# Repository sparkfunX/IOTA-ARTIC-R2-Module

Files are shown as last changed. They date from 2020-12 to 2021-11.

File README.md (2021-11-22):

# IOTA (Integrated Open-Source Transceiver for Argos)

SparkX IOTA (SPX-17984) (https://www.sparkfun.com/products/17984)

[*SparkX IOTA (SPX-17984)*](https://www.sparkfun.com/products/17984)

The [ARGOS ARTIC R2 satellite communication chipset](https://www.cls-telemetry.com/argos-solutions/argos-products/modems/artic-chipset/#1534863095666-398318f3-c367) in castellated module format.

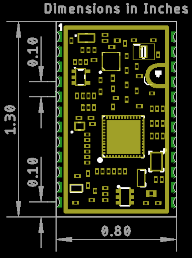
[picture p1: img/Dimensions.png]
Dimensions


The ARTIC-R2 is an integrated low power small size ARGOS 2/3/4 single chip radio. ARTIC-R2 implements a message based wireless interface. For satellite uplink communication, ARTIC-R2 will encode, modulate and transmit provided user messages. For downlink communication, ARTIC-R2 will lock to the downstream, demodulate and decode it and extract the satellite messages.

The ARTIC-R2 can transmit signals in frequency bands around 400MHz and receive signals in the bands around 466MHz, in accordance with the ARGOS satellite system specifications. The ARTIC-R2 is compliant to all ARGOS 3 and ARGOS 4 RX and TX standards. It contains a RF transceiver and frequency synthesizer and a digital baseband modem. The ARTIC-R2 contains an on-chip power amplifier delivering 1mW [0dBm] output power, that serves as an output for connecting an external high efficient PA. The (de)modulation algorithms run on an on-chip DSP. This software approach allows for retargeting the ARTIC for other applications. The DSP program can be retained on an external flash or the MCU.

- Serial interface (SPI) for communication with MCU
- Programmable DSP core on board to ensure flexibility
- RX frequency : 466MHz – TX frequency: 400MHz
- Fractional N frequency synthesis
- Supported TX standards:
  - BPSK: PTT-A2 (ARGOS 2), PTT-VLD (ARGOS 4)
  - QPSK: PTT-A3, PTT-ZE (ARGOS 3)
  - GMSK: PTT-HD (ARGOS 3), PTT-MD (ARGOS 4), PTT-HD (ARGOS 4)
- Supported RX standards:
  - BPSK: PMT-A3 (ARGOS 3)
  - DSSS OQPSK: PMT-A4 (ARGOS 4) not available
- Dedicated flash Interface to retain Firmware
- Support COSPAS-SARSAT standard
- Operates on external 26MHz reference clock
- Dual supply, 1.8V and 3.3V
- Integrated PA (0dBm) to combine with external PA

An RFPA0133 programmable gain power amplifier boosts the 0dBm (1mW) output from the ARTIC by up to 26dB, producing a maximum transmit power level of 400mW. The transmit power can be adjusted via the **G8** pad.

The ARGOS satellite system is **currently** restricted to specific programs and applications. Please check that your project meets these requirements before buying hardware. [CLS (France)](https://www.cls-telemetry.com/argos-solutions/) and the [Woods Hole Group (America)](https://www.clsamerica.com/science-with-argos) will be able to advise if your project meets the requirements.
- _**"To meet system use requirements, all programs using Argos have to be related in some way or other to environmental protection, awareness or study, or to protecting human life."**_

## Repository Contents

- [**/Documents**](./Hardware) - Datasheets, test certificates, etc.
- [**/Hardware**](./Hardware) - Eagle PCB, SCH and LBR design files
- [**LICENSE.md**](./LICENSE.md) - contains the licence information

## Documentation

- [**Arduino Library**](https://github.com/sparkfun/SparkFun_ARGOS_ARTIC_R2_Arduino_Library) - SparkFun ARGOS ARTIC R2 Arduino Library
- [**Hookup Guide**](https://learn.sparkfun.com/tutorials/iota-artic-r2-satellite-communication-module-hookup-guide) - a hookup guide for the SparkFun IOTA - Satellite Communication Module (ARTIC R2)

## Thanks

The ARTIC R2 circuit is a remix of the reference design kindly provided by the [Arribada Initiative](https://arribada.org/) and Icoteq Ltd.

## License Information

This product is _**open source**_! 

Please review the LICENSE.md file for license information. 

If you have any questions or concerns on licensing, please contact technical support on our [SparkFun forums](https://forum.sparkfun.com/viewforum.php?f=152).

Distributed as-is; no warranty is given.

- Your friends at SparkFun.

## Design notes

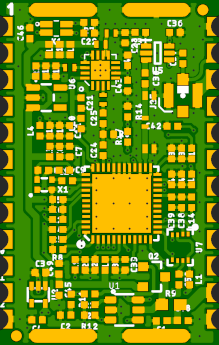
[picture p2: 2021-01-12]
img/Top.png

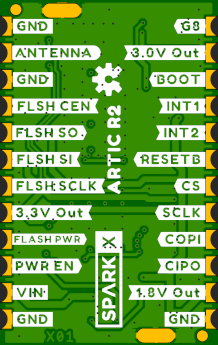
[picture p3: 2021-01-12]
img/Bottom.png

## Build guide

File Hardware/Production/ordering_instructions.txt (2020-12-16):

JLCPCB JLC7628 4-Layer 0.8mm Impedance Control
Castellated Holes
panel size, 148x148mm
PCB thickness, 0.8mm
number of layers, 4
soldermask color, Black
silkscreen color, White
oz copper, 1oz
finish, ENIG
stencils, top
pcs per panel, 20
min trace width, 0.2032mm / 0.0080in
min drill size, 0.2000mm / 0.0079in
filename to layer stackup 1/2/3/4: GTL, GL2, GL3, GBL

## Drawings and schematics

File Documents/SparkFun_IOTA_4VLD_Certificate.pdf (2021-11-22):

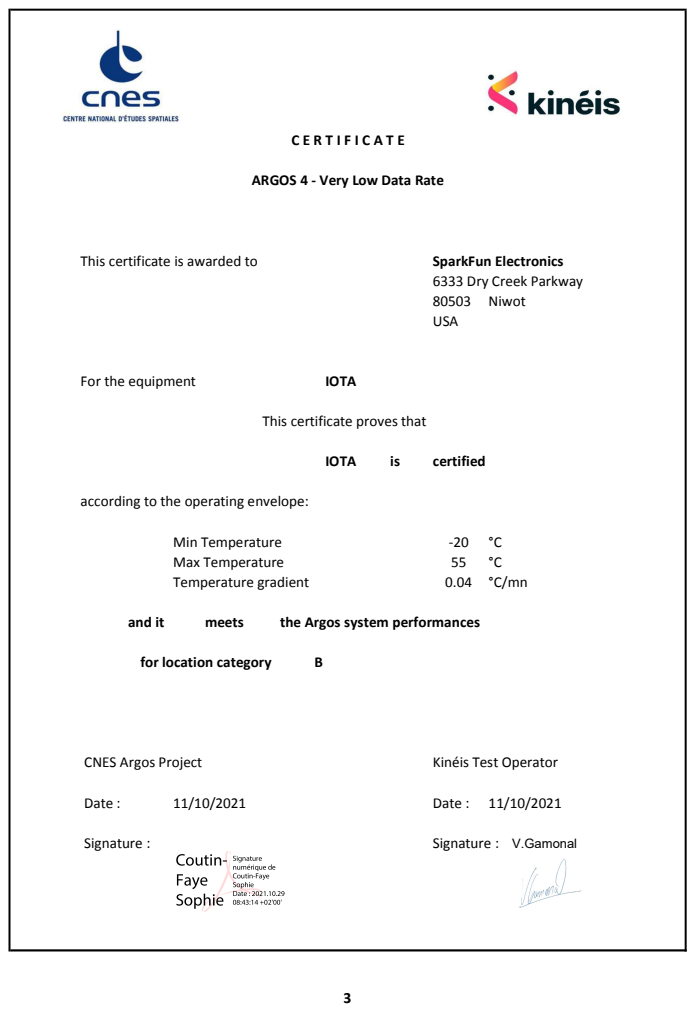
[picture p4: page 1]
This certificate is awarded to; SparkFun Electronics; For the equipment; IOTA; certified; Min Temperature; Max Temperature; Temperature gradient; and it; meets; the Argos system performances; for location category; CNES Argos Project; Kinéis Test Operator; Date :; Date : 11/10/2021; Signature :; V.Gamonal

ARGOS 4 - Very Low Data Rate

6333 Dry Creek Parkway
80503 Niwot
USA

This certificate proves that

according to the operating envelope:

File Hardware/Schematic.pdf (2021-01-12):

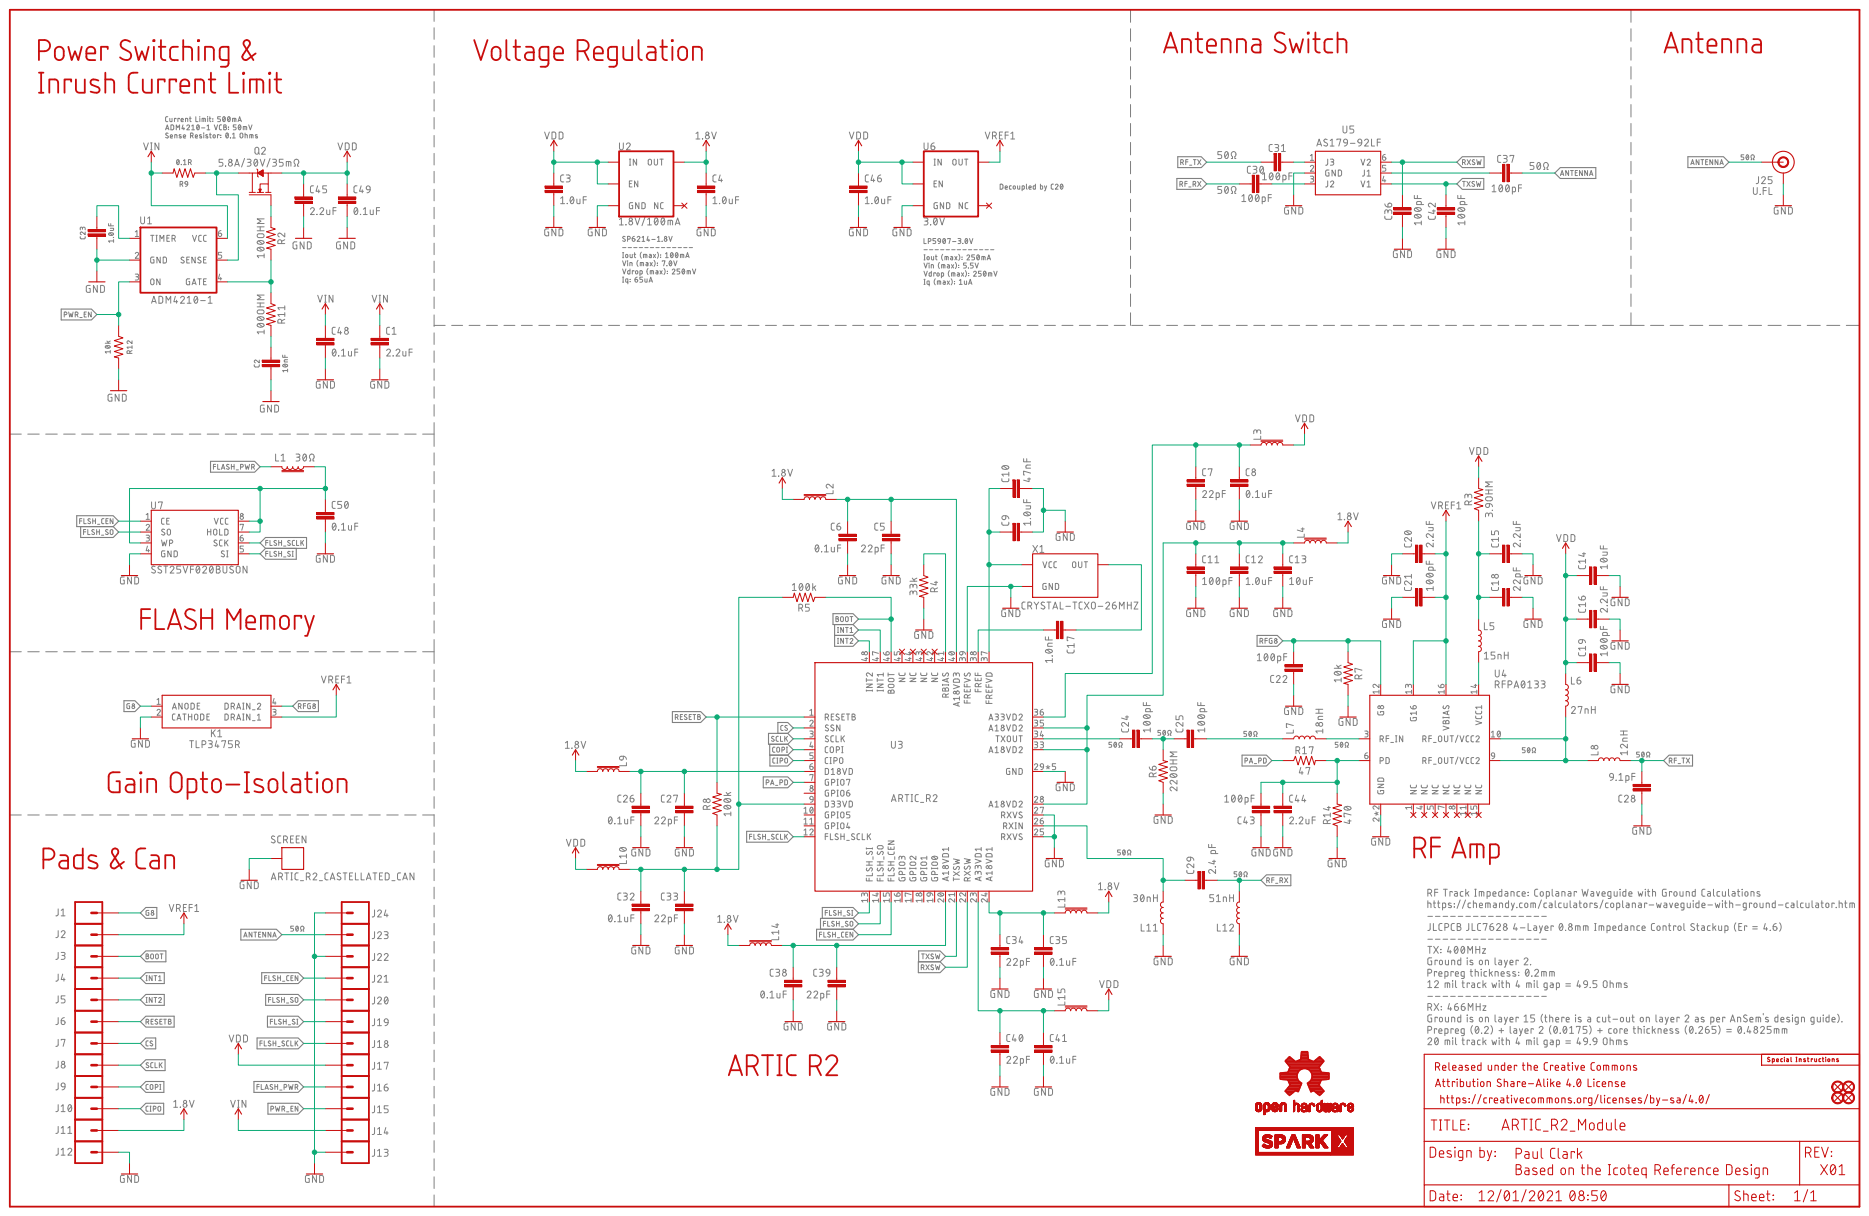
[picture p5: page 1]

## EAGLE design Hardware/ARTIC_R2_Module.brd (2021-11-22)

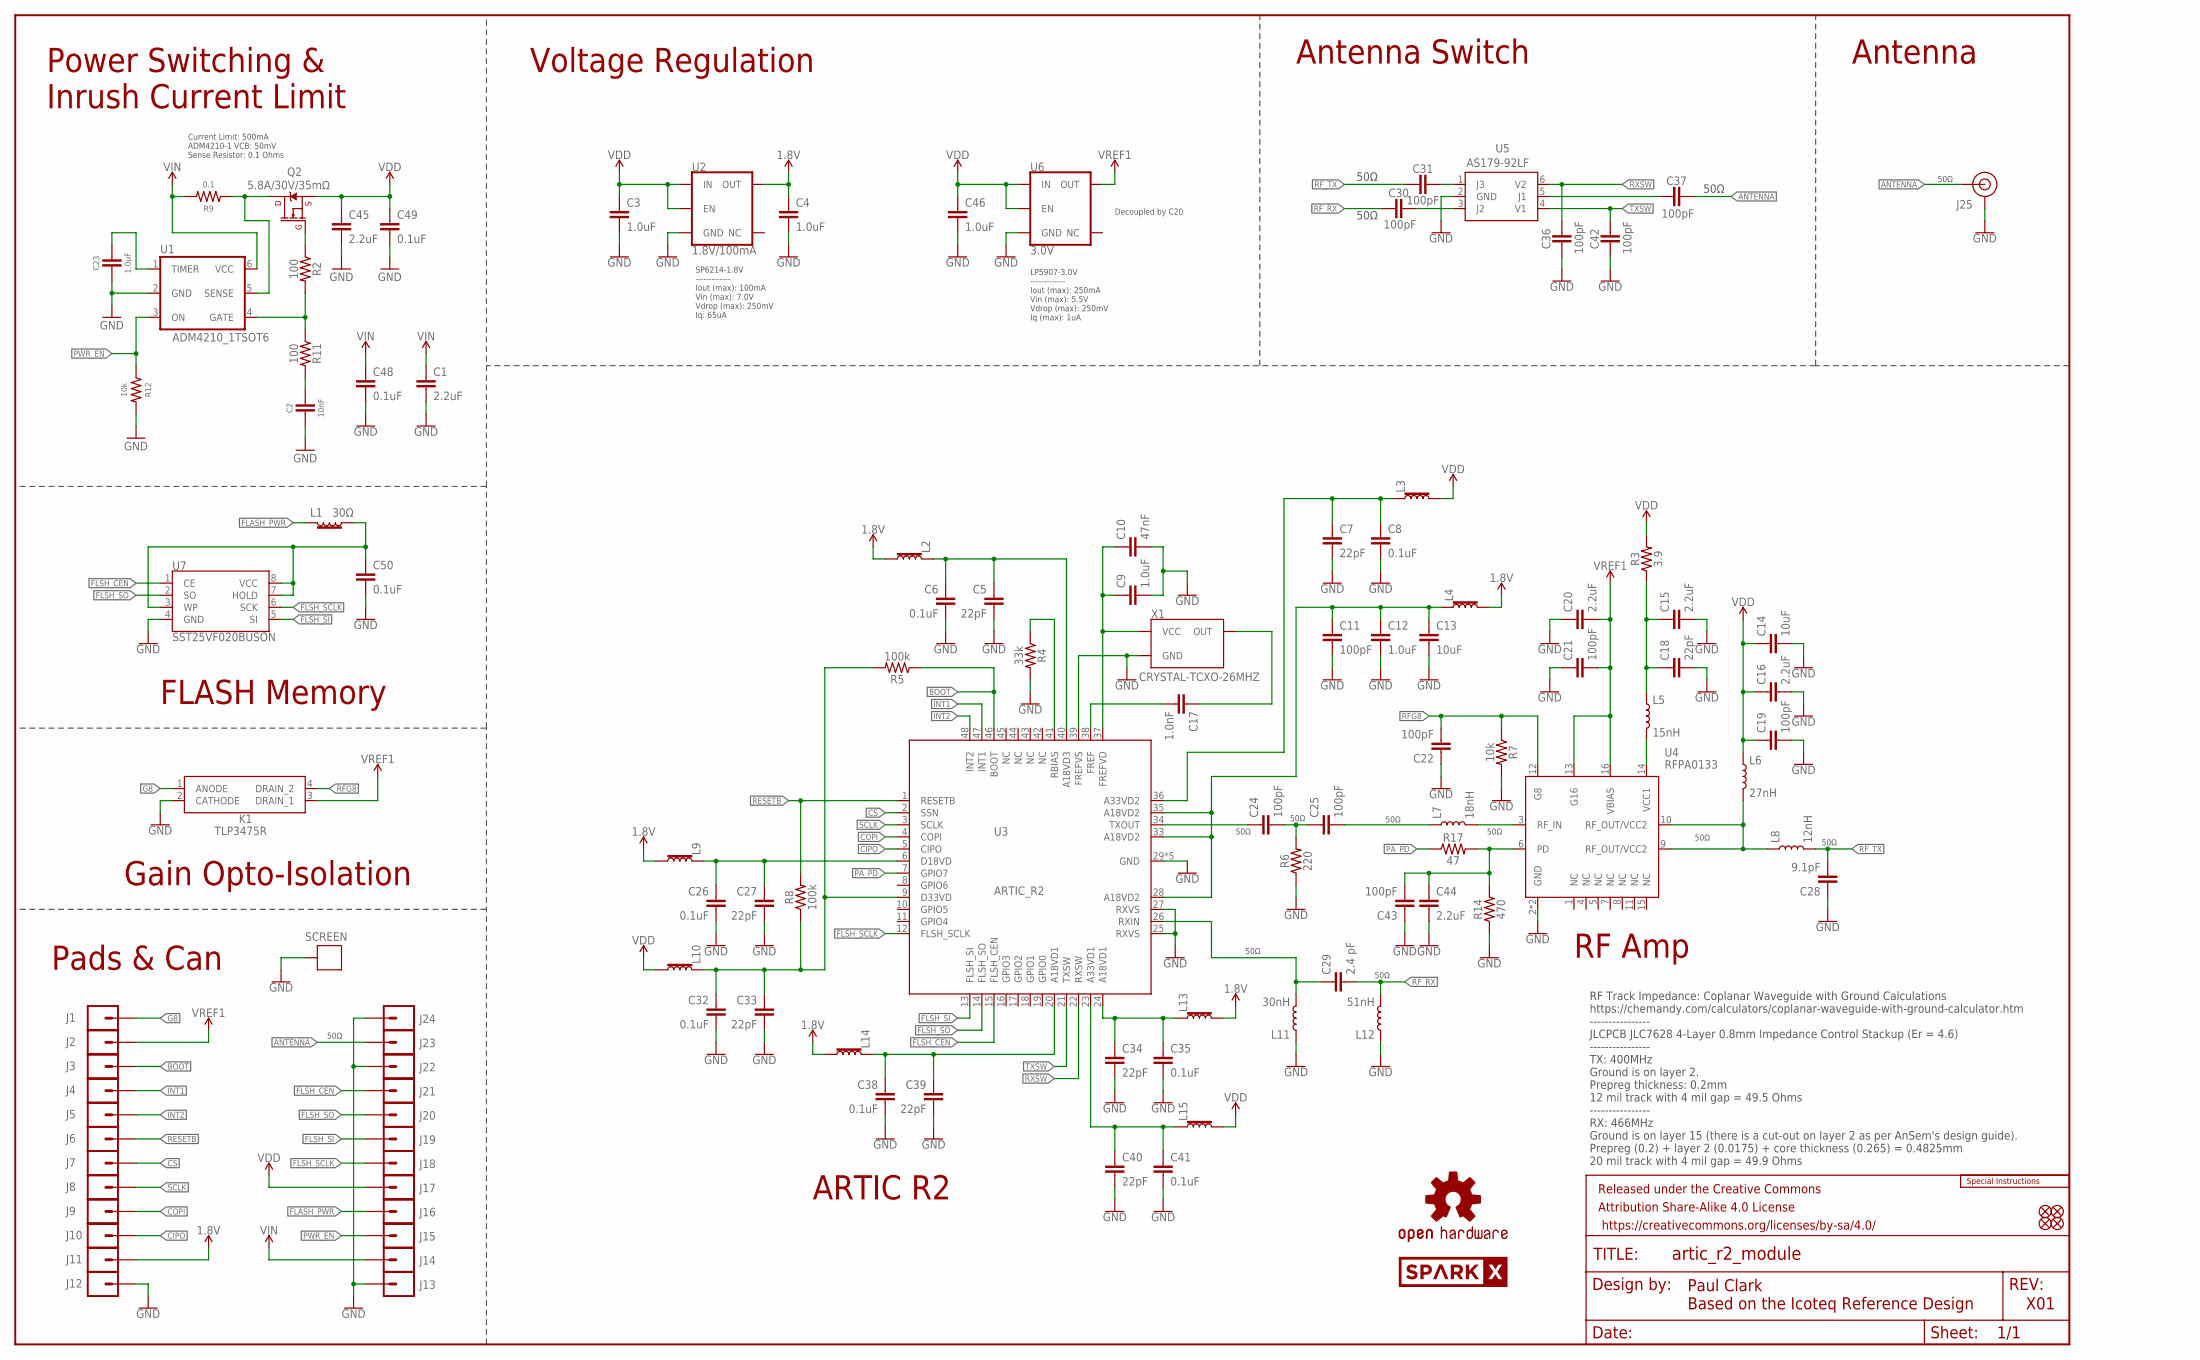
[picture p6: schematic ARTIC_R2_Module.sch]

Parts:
C1, C15, C16, C20, C44, C45: 2.2uF; 0402-TIGHT
C2: 10nF; 0402-TIGHT
C3, C4, C9, C12, C23, C46: 1.0uF; 0402-TIGHT
C5, C7, C18, C27, C33, C34, C39, C40: 22pF; 0402-TIGHT
C6, C8, C26, C32, C35, C38, C41, C48, C49, C50: 0.1uF; 0402-TIGHT
C10: 47nF; 0402-TIGHT
C11, C19, C21, C22, C24, C25, C30, C31, C36, C37, C42, C43: 100pF; 0402-TIGHT
C13, C14: 10uF; 0402-TIGHT
C17: 1.0nF; 0402-TIGHT
C28: 9.1pF; 0402-TIGHT
C29: 2.4 pF; 0402_MURATA
FD1, FD2, FD3, FD4: FIDUCIAL1X2; FIDUCIAL-1X2
FRAME1: FRAME-LEDGER; CREATIVE_COMMONS
J1, J2, J3, J4, J5, J6, J7, J8, J9, J10, J11, J12, J13, J14, J15, J16, J17, J18, J19, J20, J21, J22, J23, J24: CONN_01_CASTELLATED_4LAYERWITHOUT_VIA; CONN_01_CASTELLATED_4LAYER
J25: U.FL; U.FL_REDUCED_FOOTPRINT
K1: TLP3475R; TLP3475RTPF
L1, L2, L3, L4, L9, L10, L13, L14, L15: 30Ω; 0402-TIGHT
L5: 15nH; 0402_COILCRAFT
L6: 27nH; 0402_COILCRAFT
L7: 18nH; 0402_COILCRAFT
L8: 12nH; 0402_COILCRAFT
L11: 30nH; 0402_COILCRAFT
L12: 51nH; 0402_COILCRAFT
LOGO1: SPECIAL_INSTRUCTIONS-ORDERING; ORDERING_INSTRUCTIONS
LOGO3: OSHW-LOGOS; OSHW-LOGO-S
Q2: 5.8A/30V/35mΩ; SOT23-3
R2, R11: 100; 0402-TIGHT
R3: 3.9; 0402-TIGHT
R4: 33k; 0402-TIGHT
R5, R8: 100k; 0402-TIGHT
R6: 220; 0402-TIGHT
R7, R12: 10k; 0402-TIGHT
R9: 0.1; 0603
R14: 470; 0402-TIGHT
R17: 47; 0402-TIGHT
SCREEN: IOTA_SCREENING_CANSTRAIGHT_SLOTS; IOTA_CAN_STRAIGHT_SLOTS
SPARKX2: SPARKX-LOGO4; SPARKX-MEDIUM
U1: ADM4210_1TSOT6; TSOT6
U2: 1.8V/100mA; SC70
U3: ARTIC_R2; QFN-48
U4: RFPA0133; QFN50P300X300X86-17N
U5: AS179-92LF; SOT65P220X100-6N
U6: 3.0V; SOT23-5
U7: SST25VF020BUSON; USON_3X2MM
X1: CRYSTAL-TCXO-26MHZ; CRYSTAL-TCXO-SMD-1.65X1.25

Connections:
1.8V: C4.1, J11.1, L2.2, L4.2, L9.2, L13.2, L14.2, U2.5 (OUT)
ANTENNA: C37.1, J23.1, J25.FEED (SIGNAL)
BOOT: J3.1, R5.1, U3.46 (BOOT)
CIPO: J10.1, U3.5 (CIPO)
COPI: J9.1, U3.4 (COPI)
CS: J7.1, U3.2 (SSN)
FLASH_PWR: J16.1, L1.2
FLASH_VCC: C50.1, L1.1, U7.3 (WP), U7.7 (HOLD), U7.8 (VCC)
FLSH_CEN: J21.1, U3.15 (FLSH_CEN), U7.1 (CE)
FLSH_SCLK: J18.1, U3.12 (FLSH_SCLK), U7.6 (SCK)
FLSH_SI: J19.1, U3.13 (FLSH_SI), U7.5 (SI)
FLSH_SO: J20.1, U3.14 (FLSH_SO), U7.2 (SO)
G8: J1.1, K1.1 (ANODE)
GND: C1.2, C2.2, C3.2, C4.2, C5.2, C6.2, C7.2, C8.2, C9.2, C10.2, C11.2, C12.2, C13.2, C14.2, C15.2, C16.2, C18.2, C19.2, C20.1, C21.1, C22.1, C23.2, C26.2, C27.2, C28.1, C32.2, C33.2, C34.2, C35.2, C36.2, C38.2, C39.2, C40.2, C41.2, C42.2, C43.1, C44.2, C45.2, C46.2, C48.2, C49.2, C50.2, J12.1, J13.1, J22.1, J24.1, J25.1 (GND), J25.2 (GND), K1.2 (CATHODE), L11.P$1 (1), L12.P$1 (1), R4.2, R6.1, R7.2, R12.2, R14.1, SCREEN.1-1, SCREEN.1-16, SCREEN.2, SCREEN.3-1, SCREEN.3-16, SCREEN.4, U1.2 (GND), U2.2 (GND), U3.25 (RXVS), U3.27 (RXVS), U3.29 (GND), U3.30 (GND), U3.31 (GND), U3.32 (GND), U3.39 (FREFVS), U3.GND, U4.2 (GND), U4.EDAP (GND), U5.2 (GND), U6.2 (GND), U7.4 (GND), X1.1 (GND), X1.2 (GND)
INT1: J4.1, U3.47 (INT1)
INT2: J5.1, U3.48 (INT2)
unnamed: Q2.3 (D), R9.1, U1.5 (SENSE)
unnamed: Q2.1 (G), R2.1
unnamed: R2.2, R11.1, U1.4 (GATE)
unnamed: C34.1, C35.1, L13.1, U3.24 (A18VD1)
unnamed: C40.1, C41.1, L15.1, U3.23 (A33VD1)
unnamed: C2.1, R11.2
unnamed: C23.1, U1.1 (TIMER)
unnamed: C26.1, C27.1, L9.1, U3.6 (D18VD)
unnamed: C32.1, C33.1, L10.1, R5.2, R8.1, U3.9 (D33VD)
unnamed: C11.1, C12.1, C13.1, L4.1, U3.28 (A18VD2), U3.33 (A18VD2), U3.35 (A18VD2)
unnamed: C7.1, C8.1, L3.1, U3.36 (A33VD2)
unnamed: R4.1, U3.41 (RBIAS)
unnamed: C5.1, C6.1, L2.1, U3.40 (A18VD3)
unnamed: C9.1, C10.1, U3.37 (FREFVD), X1.4 (VCC)
unnamed: C17.1, X1.3 (OUT)
unnamed: C17.2, U3.38 (FREF)
unnamed: C24.1, U3.34 (TXOUT)
unnamed: C24.2, C25.1, R6.2
unnamed: L5.P$2 (2), U4.14 (VCC1)
unnamed: C15.1, C18.1, L5.P$1 (1), R3.1
unnamed: C29.P$1 (1), L11.P$2 (2), U3.26 (RXIN)
unnamed: C25.2, L7.P$1 (1)
unnamed: L7.P$2 (2), U4.3 (RF_IN)
unnamed: L6.P$2 (2), L8.P$1 (1), U4.9 (RF_OUT/VCC2), U4.10 (RF_OUT/VCC2)
unnamed: C31.1, U5.1 (J3)
unnamed: C30.1, U5.3 (J2)
unnamed: C37.2, U5.5 (J1)
unnamed: C38.1, C39.1, L14.1, U3.20 (A18VD1)
PA_PD: R17.1, U3.7 (GPIO7)
PD: C43.2, C44.1, R14.2, R17.2, U4.6 (PD)
PWR_EN: J15.1, R12.1, U1.3 (ON)
RESETB: J6.1, R8.2, U3.1 (RESETB)
RFG8: C22.2, K1.4 (DRAIN_2), R7.1, U4.12 (G8)
RF_RX: C29.P$2 (2), C30.2, L12.P$2 (2)
RF_TX: C28.2, C31.2, L8.P$2 (2)
RXSW: C36.1, U3.22 (RXSW), U5.6 (V2)
SCLK: J8.1, U3.3 (SCLK)
TXSW: C42.1, U3.21 (TXSW), U5.4 (V1)
VDD: C3.1, C14.1, C16.1, C19.1, C45.1, C46.1, C49.1, J17.1, L3.2, L6.P$1 (1), L10.2, L15.2, Q2.2 (S), R3.2, U2.1 (IN), U2.3 (EN), U6.1 (IN), U6.3 (EN)
VIN: C1.1, C48.1, J14.1, R9.2, U1.6 (VCC)
VREF1: C20.2, C21.2, J2.1, K1.3 (DRAIN_1), U4.13 (G16), U4.16 (VBIAS), U6.5 (OUT)

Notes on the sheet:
Paul Clark Based on the Icoteq Reference Design
X01
SP6214-1.8V ------------- Iout (max): 100mA Vin (max): 7.0V Vdrop (max): 250mV Iq: 65uA
Voltage Regulation
Antenna Switch
Antenna
ARTIC R2
RF Amp
Pads & Can
50Ω
RF Track Impedance: Coplanar Waveguide with Ground Calculations https://chemandy.com/calculators/coplanar-waveguide-with-ground-calculator.htm ---------------- JLCPCB JLC7628 4-Layer 0.8mm Impedance Control Stackup (Er = 4.6) ---------------- TX: 400MHz Ground is on layer 2. Prepreg thickness: 0.2m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
Gain Opto-Isolation
LP5907-3.0V ------------- Iout (max): 250mA Vin (max): 5.5V Vdrop (max): 250mV Iq (max): 1uA
Decoupled by C20
Power Switching & Inrush Current Limit
Current Limit: 500mA ADM4210-1 VCB: 50mV Sense Resistor: 0.1 Ohms
FLASH Memory

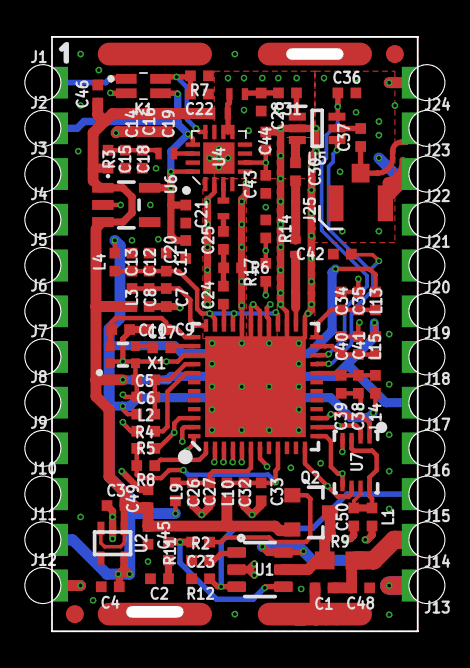
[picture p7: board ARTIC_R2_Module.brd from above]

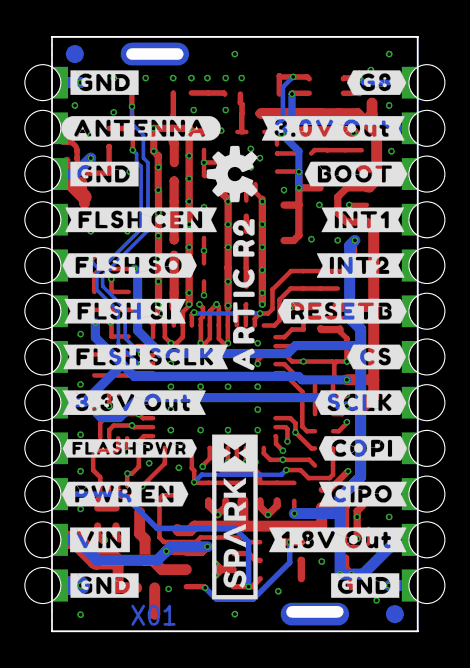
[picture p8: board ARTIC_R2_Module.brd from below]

Board: 4 copper layers, 20.3 x 33.0 mm, 146 parts (29 on the bottom side), 57 nets.

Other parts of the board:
U$1, U$3, U$4, U$5: #GND#0
U$2: 10
U$6: #PWR_EN#0
U$7: #VIN#0
U$8: #FLASH_PWR#0
U$9: #FLSH_SCLK#0
U$10: #FLSH_SI#0
U$11: #FLSH_SO#0
U$12: #FLSH_CEN#0
U$13: #3#3V_OUT#0
U$14: #ANTENNA#0
U$15: #G8#0
U$16: #3#0V_OUT#0
U$17: #BOOT#0
U$18: #INT1#0
U$19: #INT2#0
U$20: #RESETB#0
U$21: #CS#0
U$22: #SCLK#0
U$23: #COPI#0
U$24: #CIPO#0
U$25: #1#8V_OUT#0
U$26: ARTIC_R20

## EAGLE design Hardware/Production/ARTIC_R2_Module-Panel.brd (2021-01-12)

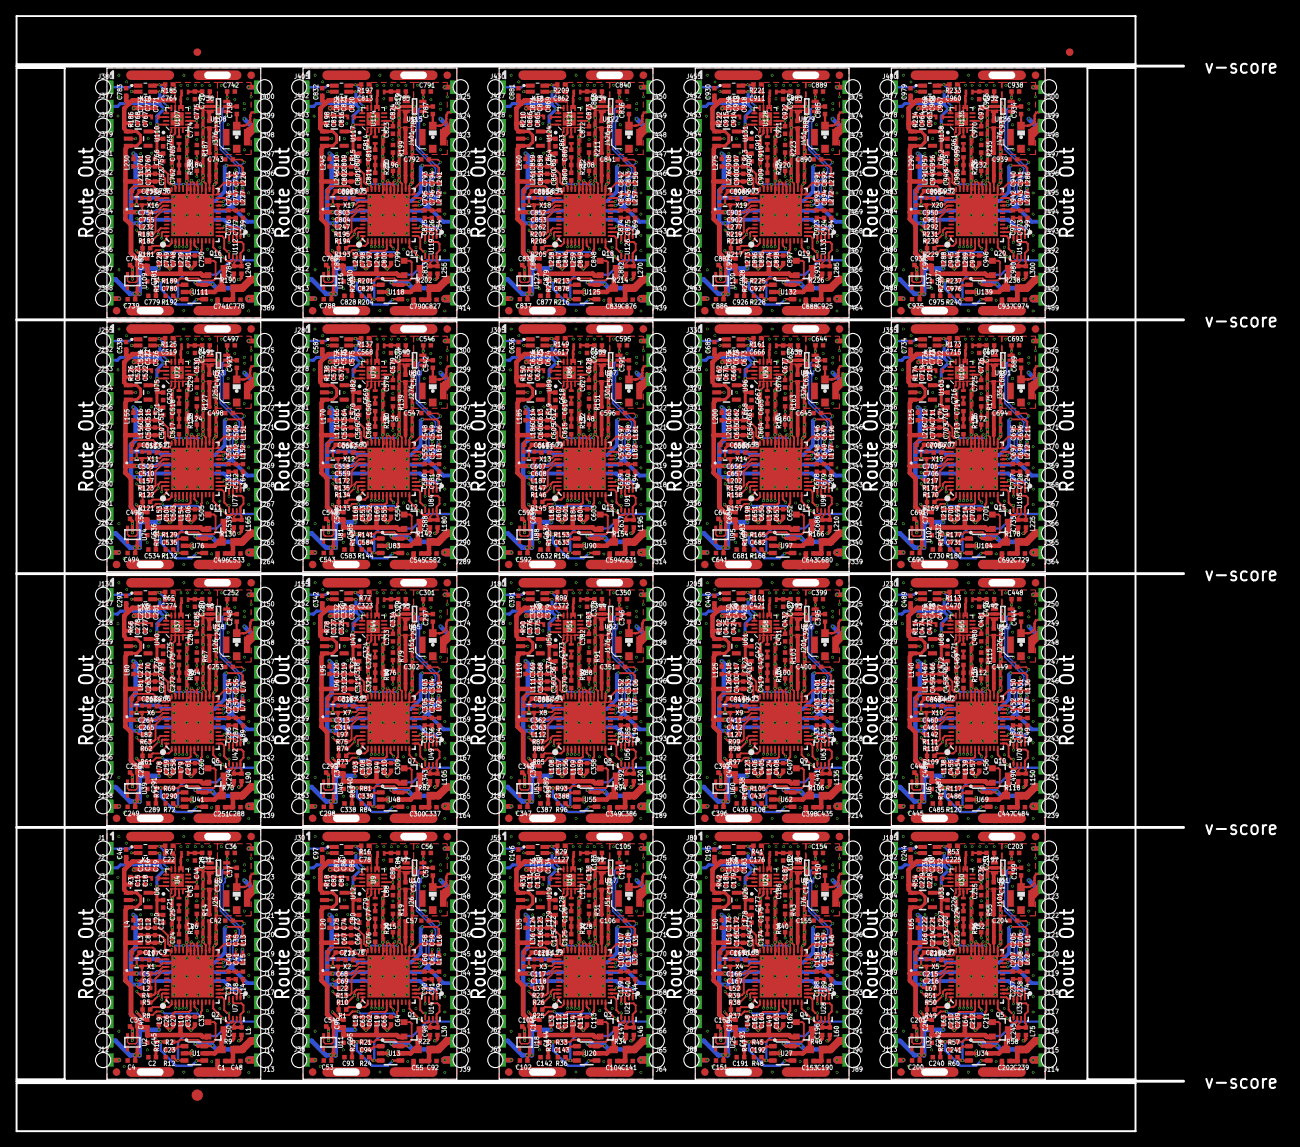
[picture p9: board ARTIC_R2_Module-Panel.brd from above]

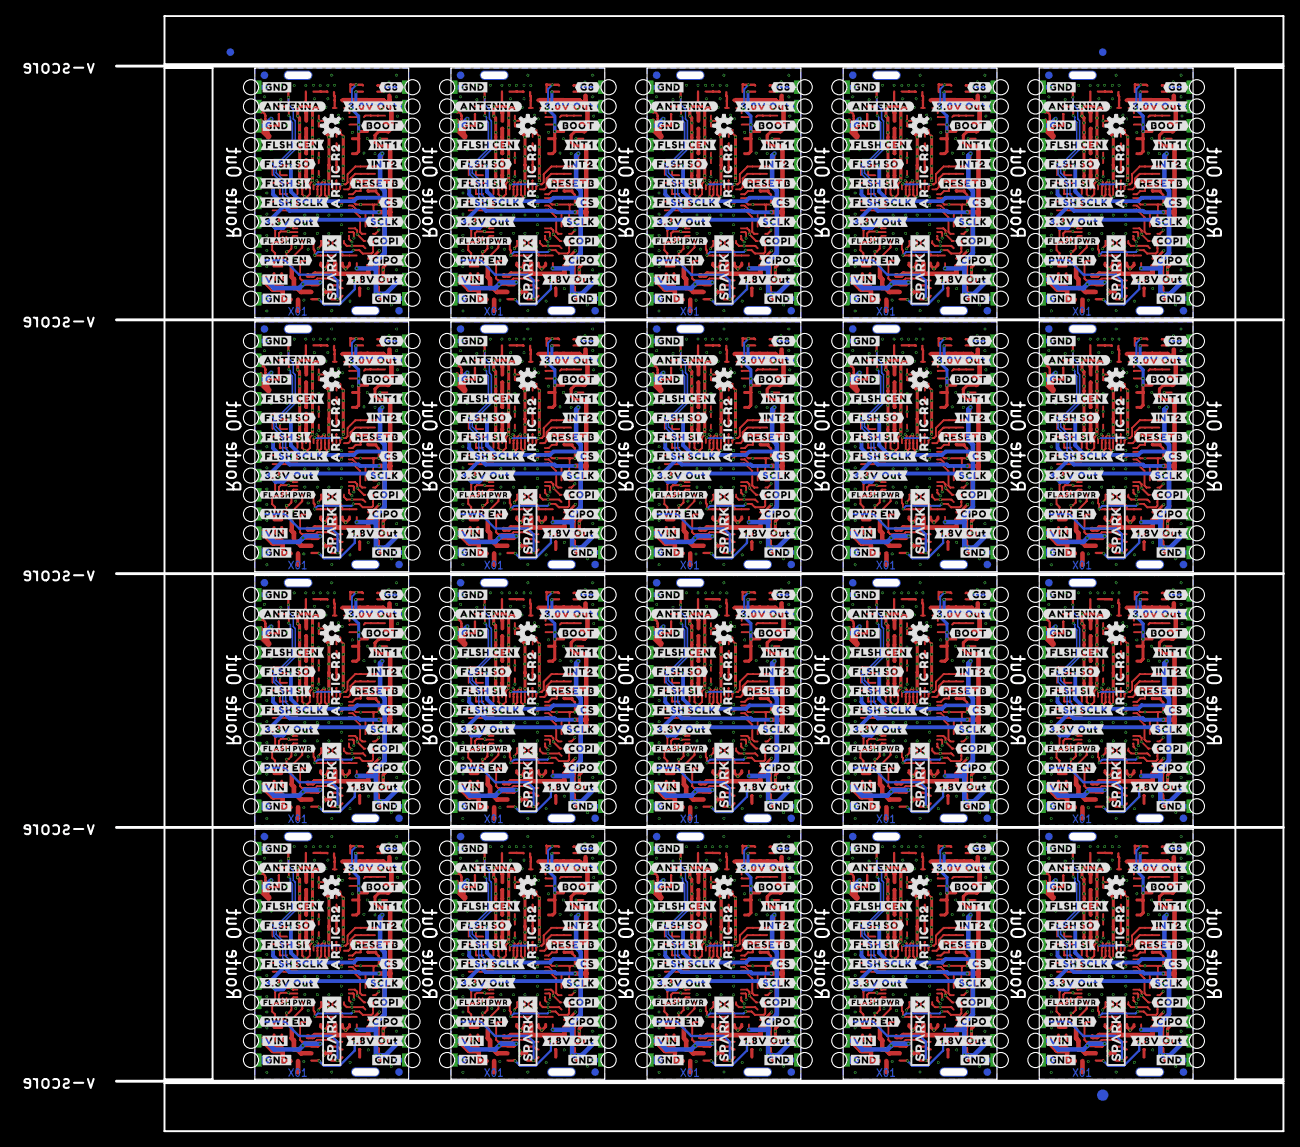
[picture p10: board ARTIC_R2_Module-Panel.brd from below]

Board: 4 copper layers, 154.2 x 147.3 mm, 2886 parts (583 on the bottom side), 1140 nets.

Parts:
C1, C15, C16, C20, C44, C45, C55, C80, C82, C86, C89, C95, C104, C129, C131, C135, C138, C144, C153, C178, C180, C184, C187, C193, C202, C227, C229, C233, C236, C242, C251, C276, C278, C282, C285, C291, C300, C325, C327, C331, C334, C340, C349, C374, C376, C380, C383, C389, C398, C423, C425, C429, C432, C438, C447, C472, C474, C478, C481, C487, C496, C521, C523, C527, C530, C536, C545, C570, C572, C576, C579, C585, C594, C619, C621, C625, C628, C634, C643, C668, C670, C674, C677, C683, C692, C717, C719, C723, C726, C732, C741, C766, C768, C772, C775, C781, C790, C815, C817, C821, C824, C830, C839, C864, C866, C870, C873, C879, C888, C913, C915, C919, C922, C928, C937, C962, C964, C968, C971, C977: 2.2uF; 0402-TIGHT
C2, C93, C142, C191, C240, C289, C338, C387, C436, C485, C534, C583, C632, C681, C730, C779, C828, C877, C926, C975: 10nF; 0402-TIGHT
C3, C4, C9, C12, C23, C46, C53, C54, C70, C74, C94, C97, C102, C103, C119, C123, C143, C146, C151, C152, C168, C172, C192, C195, C200, C201, C217, C221, C241, C244, C249, C250, C266, C270, C290, C293, C298, C299, C315, C319, C339, C342, C347, C348, C364, C368, C388, C391, C396, C397, C413, C417, C437, C440, C445, C446, C462, C466, C486, C489, C494, C495, C511, C515, C535, C538, C543, C544, C560, C564, C584, C587, C592, C593, C609, C613, C633, C636, C641, C642, C658, C662, C682, C685, C690, C691, C707, C711, C731, C734, C739, C740, C756, C760, C780, C783, C788, C789, C805, C809, C829, C832, C837, C838, C854, C858, C878, C881, C886, C887, C903, C907, C927, C930, C935, C936, C952, C956, C976, C979: 1.0uF; 0402-TIGHT
C5, C7, C18, C27, C33, C34, C39, C40, C58, C60, C62, C64, C66, C68, C81, C90, C107, C109, C111, C113, C115, C117, C130, C139, C156, C158, C160, C162, C164, C166, C179, C188, C205, C207, C209, C211, C213, C215, C228, C237, C254, C256, C258, C260, C262, C264, C277, C286, C303, C305, C307, C309, C311, C313, C326, C335, C352, C354, C356, C358, C360, C362, C375, C384, C401, C403, C405, C407, C409, C411, C424, C433, C450, C452, C454, C456, C458, C460, C473, C482, C499, C501, C503, C505, C507, C509, C522, C531, C548, C550, C552, C554, C556, C558, C571, C580, C597, C599, C601, C603, C605, C607, C620, C629, C646, C648, C650, C652, C654, C656, C669, C678, C695, C697, C699, C701, C703, C705, C718, C727, C744, C746, C748, C750, C752, C754, C767, C776, C793, C795, C797, C799, C801, C803, C816, C825, C842, C844, C846, C848, C850, C852, C865, C874, C891, C893, C895, C897, C899, C901, C914, C923, C940, C942, C944, C946, C948, C950, C963, C972: 22pF; 0402-TIGHT
C6, C8, C26, C32, C35, C38, C41, C48, C49, C50, C59, C61, C63, C65, C67, C69, C91, C92, C96, C98, C108, C110, C112, C114, C116, C118, C140, C141, C145, C147, C157, C159, C161, C163, C165, C167, C189, C190, C194, C196, C206, C208, C210, C212, C214, C216, C238, C239, C243, C245, C255, C257, C259, C261, C263, C265, C287, C288, C292, C294, C304, C306, C308, C310, C312, C314, C336, C337, C341, C343, C353, C355, C357, C359, C361, C363, C385, C386, C390, C392, C402, C404, C406, C408, C410, C412, C434, C435, C439, C441, C451, C453, C455, C457, C459, C461, C483, C484, C488, C490, C500, C502, C504, C506, C508, C510, C532, C533, C537, C539, C549, C551, C553, C555, C557, C559, C581, C582, C586, C588, C598, C600, C602, C604, C606, C608, C630, C631, C635, C637, C647, C649, C651, C653, C655, C657, C679, C680, C684, C686, C696, C698, C700, C702, C704, C706, C728, C729, C733, C735, C745, C747, C749, C751, C753, C755, C777, C778, C782, C784, C794, C796, C798, C800, C802, C804, C826, C827, C831, C833, C843, C845, C847, C849, C851, C853, C875, C876, C880, C882, C892, C894, C896, C898, C900, C902, C924, C925, C929, C931, C941, C943, C945, C947, C949, C951, C973, C974, C978, C980: 0.1uF; 0402-TIGHT
C10, C71, C120, C169, C218, C267, C316, C365, C414, C463, C512, C561, C610, C659, C708, C757, C806, C855, C904, C953: 47nF; 0402-TIGHT
C11, C19, C21, C22, C24, C25, C30, C31, C36, C37, C42, C43, C47, C51, C52, C56, C57, C73, C76, C77, C78, C79, C85, C88, C99, C100, C101, C105, C106, C122, C125, C126, C127, C128, C134, C137, C148, C149, C150, C154, C155, C171, C174, C175, C176, C177, C183, C186, C197, C198, C199, C203, C204, C220, C223, C224, C225, C226, C232, C235, C246, C247, C248, C252, C253, C269, C272, C273, C274, C275, C281, C284, C295, C296, C297, C301, C302, C318, C321, C322, C323, C324, C330, C333, C344, C345, C346, C350, C351, C367, C370, C371, C372, C373, C379, C382, C393, C394, C395, C399, C400, C416, C419, C420, C421, C422, C428, C431, C442, C443, C444, C448, C449, C465, C468, C469, C470, C471, C477, C480, C491, C492, C493, C497, C498, C514, C517, C518, C519, C520, C526, C529, C540, C541, C542, C546, C547, C563, C566, C567, C568, C569, C575, C578, C589, C590, C591, C595, C596, C612, C615, C616, C617, C618, C624, C627, C638, C639, C640, C644, C645, C661, C664, C665, C666, C667, C673, C676, C687, C688, C689, C693, C694, C710, C713, C714, C715, C716, C722, C725, C736, C737, C738, C742, C743, C759, C762, C763, C764, C765, C771, C774, C785, C786, C787, C791, C792, C808, C811, C812, C813, C814, C820, C823, C834, C835, C836, C840, C841, C857, C860, C861, C862, C863, C869, C872, C883, C884, C885, C889, C890, C906, C909, C910, C911, C912, C918, C921, C932, C933, C934, C938, C939, C955, C958, C959, C960, C961, C967, C970: 100pF; 0402-TIGHT
C13, C14, C75, C87, C124, C136, C173, C185, C222, C234, C271, C283, C320, C332, C369, C381, C418, C430, C467, C479, C516, C528, C565, C577, C614, C626, C663, C675, C712, C724, C761, C773, C810, C822, C859, C871, C908, C920, C957, C969: 10uF; 0402-TIGHT
C17, C72, C121, C170, C219, C268, C317, C366, C415, C464, C513, C562, C611, C660, C709, C758, C807, C856, C905, C954: 1.0nF; 0402-TIGHT
C28, C84, C133, C182, C231, C280, C329, C378, C427, C476, C525, C574, C623, C672, C721, C770, C819, C868, C917, C966: 9.1pF; 0402-TIGHT
C29, C83, C132, C181, C230, C279, C328, C377, C426, C475, C524, C573, C622, C671, C720, C769, C818, C867, C916, C965: 2.4 pF; 0402_MURATA
E$1, E$2, E$3, E$4: FIDUCIAL-1X2
E$5, E$6: FIDUCIAL-1.5X3
FD1, FD2, FD3, FD4, FD5, FD6, FD7, FD8, FD9, FD10, FD11, FD12, FD13, FD14, FD15, FD16, FD17, FD18, FD19, FD20, FD21, FD22, FD23, FD24, FD25, FD26, FD27, FD28, FD29, FD30, FD31, FD32, FD33, FD34, FD35, FD36, FD37, FD38, FD39, FD40, FD41, FD42, FD43, FD44, FD45, FD46, FD47, FD48, FD49, FD50, FD51, FD52, FD53, FD54, FD55, FD56, FD57, FD58, FD59, FD60, FD61, FD62, FD63, FD64, FD65, FD66, FD67, FD68, FD69, FD70, FD71, FD72, FD73, FD74, FD75, FD76, FD77, FD78, FD79, FD80: FIDUCIAL1X2; FIDUCIAL-1X2
J1, J2, J3, J4, J5, J6, J7, J8, J9, J10, J11, J12, J13, J14, J15, J16, J17, J18, J19, J20, J21, J22, J23, J24, J27, J28, J29, J30, J31, J32, J33, J34, J35, J36, J37, J38, J39, J40, J41, J42, J43, J44, J45, J46, J47, J48, J49, J50, J52, J53, J54, J55, J56, J57, J58, J59, J60, J61, J62, J63, J64, J65, J66, J67, J68, J69, J70, J71, J72, J73, J74, J75, J77, J78, J79, J80, J81, J82, J83, J84, J85, J86, J87, J88, J89, J90, J91, J92, J93, J94, J95, J96, J97, J98, J99, J100, J102, J103, J104, J105, J106, J107, J108, J109, J110, J111, J112, J113, J114, J115, J116, J117, J118, J119, J120, J121, J122, J123, J124, J125, J127, J128, J129, J130, J131, J132, J133, J134, J135, J136, J137, J138, J139, J140, J141, J142, J143, J144, J145, J146, J147, J148, J149, J150, J152, J153, J154, J155, J156, J157, J158, J159, J160, J161, J162, J163, J164, J165, J166, J167, J168, J169, J170, J171, J172, J173, J174, J175, J177, J178, J179, J180, J181, J182, J183, J184, J185, J186, J187, J188, J189, J190, J191, J192, J193, J194, J195, J196, J197, J198, J199, J200, J202, J203, J204, J205, J206, J207, J208, J209, J210, J211, J212, J213, J214, J215, J216, J217, J218, J219, J220, J221, J222, J223, J224, J225, J227, J228, J229, J230, J231, J232, J233, J234, J235, J236, J237, J238, J239, J240, J241, J242, J243, J244, J245, J246, J247, J248, J249, J250, J252, J253, J254, J255, J256, J257, J258, J259, J260, J261, J262, J263, J264, J265, J266, J267, J268, J269, J270, J271, J272, J273, J274, J275, J277, J278, J279, J280, J281, J282, J283, J284, J285, J286, J287, J288, J289, J290, J291, J292, J293, J294, J295, J296, J297, J298, J299, J300, J302, J303, J304, J305, J306, J307, J308, J309, J310, J311, J312, J313, J314, J315, J316, J317, J318, J319, J320, J321, J322, J323, J324, J325, J327, J328, J329, J330, J331, J332, J333, J334, J335, J336, J337, J338, J339, J340, J341, J342, J343, J344, J345, J346, J347, J348, J349, J350, J352, J353, J354, J355, J356, J357, J358, J359, J360, J361, J362, J363, J364, J365, J366, J367, J368, J369, J370, J371, J372, J373, J374, J375, J377, J378, J379, J380, J381, J382, J383, J384, J385, J386, J387, J388, J389, J390, J391, J392, J393, J394, J395, J396, J397, J398, J399, J400, J402, J403, J404, J405, J406, J407, J408, J409, J410, J411, J412, J413, J414, J415, J416, J417, J418, J419, J420, J421, J422, J423, J424, J425, J427, J428, J429, J430, J431, J432, J433, J434, J435, J436, J437, J438, J439, J440, J441, J442, J443, J444, J445, J446, J447, J448, J449, J450, J452, J453, J454, J455, J456, J457, J458, J459, J460, J461, J462, J463, J464, J465, J466, J467, J468, J469, J470, J471, J472, J473, J474, J475, J477, J478, J479, J480, J481, J482, J483, J484, J485, J486, J487, J488, J489, J490, J491, J492, J493, J494, J495, J496, J497, J498, J499, J500: CONN_01_CASTELLATED_4LAYER
J25, J26, J51, J76, J101, J126, J151, J176, J201, J226, J251, J276, J301, J326, J351, J376, J401, J426, J451, J476: U.FL
K1, K2, K3, K4, K5, K6, K7, K8, K9, K10, K11, K12, K13, K14, K15, K16, K17, K18, K19, K20: TLP3475R; TLP3475RTPF
L1, L2, L3, L4, L9, L10, L13, L14, L15, L16, L17, L18, L19, L20, L21, L22, L29, L30, L31, L32, L33, L34, L35, L36, L37, L44, L45, L46, L47, L48, L49, L50, L51, L52, L59, L60, L61, L62, L63, L64, L65, L66, L67, L74, L75, L76, L77, L78, L79, L80, L81, L82, L89, L90, L91, L92, L93, L94, L95, L96, L97, L104, L105, L106, L107, L108, L109, L110, L111, L112, L119, L120, L121, L122, L123, L124, L125, L126, L127, L134, L135, L136, L137, L138, L139, L140, L141, L142, L149, L150, L151, L152, L153, L154, L155, L156, L157, L164, L165, L166, L167, L168, L169, L170, L171, L172, L179, L180, L181, L182, L183, L184, L185, L186, L187, L194, L195, L196, L197, L198, L199, L200, L201, L202, L209, L210, L211, L212, L213, L214, L215, L216, L217, L224, L225, L226, L227, L228, L229, L230, L231, L232, L239, L240, L241, L242, L243, L244, L245, L246, L247, L254, L255, L256, L257, L258, L259, L260, L261, L262, L269, L270, L271, L272, L273, L274, L275, L276, L277, L284, L285, L286, L287, L288, L289, L290, L291, L292, L299, L300: 30Ω; 0402-TIGHT
L5, L24, L39, L54, L69, L84, L99, L114, L129, L144, L159, L174, L189, L204, L219, L234, L249, L264, L279, L294: 15nH; 0402_COILCRAFT
L6, L25, L40, L55, L70, L85, L100, L115, L130, L145, L160, L175, L190, L205, L220, L235, L250, L265, L280, L295: 27nH; 0402_COILCRAFT
L7, L23, L38, L53, L68, L83, L98, L113, L128, L143, L158, L173, L188, L203, L218, L233, L248, L263, L278, L293: 18nH; 0402_COILCRAFT
L8, L26, L41, L56, L71, L86, L101, L116, L131, L146, L161, L176, L191, L206, L221, L236, L251, L266, L281, L296: 12nH; 0402_COILCRAFT
L11, L27, L42, L57, L72, L87, L102, L117, L132, L147, L162, L177, L192, L207, L222, L237, L252, L267, L282, L297: 30nH; 0402_COILCRAFT
L12, L28, L43, L58, L73, L88, L103, L118, L133, L148, L163, L178, L193, L208, L223, L238, L253, L268, L283, L298: 51nH; 0402_COILCRAFT
LOGO1, LOGO2, LOGO3, LOGO4, LOGO5, LOGO6, LOGO7, LOGO8, LOGO9, LOGO10, LOGO11, LOGO12, LOGO13, LOGO14, LOGO15, LOGO16, LOGO17, LOGO18, LOGO19, LOGO20: OSHW-LOGOS; OSHW-LOGO-S
Q1, Q2, Q3, Q4, Q5, Q6, Q7, Q8, Q9, Q10, Q11, Q12, Q13, Q14, Q15, Q16, Q17, Q18, Q19, Q20: 5.8A/30V/35mΩ; SOT23-3
R1, R5, R8, R10, R25, R26, R37, R38, R49, R50, R61, R62, R73, R74, R85, R86, R97, R98, R109, R110, R121, R122, R133, R134, R145, R146, R157, R158, R169, R170, R181, R182, R193, R194, R205, R206, R217, R218, R229, R230: 100k; 0402-TIGHT
R2, R11, R21, R23, R33, R35, R45, R47, R57, R59, R69, R71, R81, R83, R93, R95, R105, R107, R117, R119, R129, R131, R141, R143, R153, R155, R165, R167, R177, R179, R189, R191, R201, R203, R213, R215, R225, R227, R237, R239: 100OHM; 0402-TIGHT
R3, R18, R30, R42, R54, R66, R78, R90, R102, R114, R126, R138, R150, R162, R174, R186, R198, R210, R222, R234: 3.9OHM; 0402-TIGHT
R4, R13, R27, R39, R51, R63, R75, R87, R99, R111, R123, R135, R147, R159, R171, R183, R195, R207, R219, R231: 33k; 0402-TIGHT
R6, R15, R28, R40, R52, R64, R76, R88, R100, R112, R124, R136, R148, R160, R172, R184, R196, R208, R220, R232: 220OHM; 0402-TIGHT
R7, R12, R16, R24, R29, R36, R41, R48, R53, R60, R65, R72, R77, R84, R89, R96, R101, R108, R113, R120, R125, R132, R137, R144, R149, R156, R161, R168, R173, R180, R185, R192, R197, R204, R209, R216, R221, R228, R233, R240: 10k; 0402-TIGHT
R9, R22, R34, R46, R58, R70, R82, R94, R106, R118, R130, R142, R154, R166, R178, R190, R202, R214, R226, R238: 0.1R; 0603
R14, R19, R31, R43, R55, R67, R79, R91, R103, R115, R127, R139, R151, R163, R175, R187, R199, R211, R223, R235: 470; 0402-TIGHT
R17, R20, R32, R44, R56, R68, R80, R92, R104, R116, R128, R140, R152, R164, R176, R188, R200, R212, R224, R236: 47; 0402-TIGHT
SCREEN, SCREEN1, SCREEN2, SCREEN3, SCREEN4, SCREEN5, SCREEN6, SCREEN7, SCREEN8, SCREEN9, SCREEN10, SCREEN11, SCREEN12, SCREEN13, SCREEN14, SCREEN15, SCREEN16, SCREEN17, SCREEN18, SCREEN19: ARTIC_R2_CASTELLATED_CAN; ARTIC_R2_CASTELLATED
SPARKX1, SPARKX2, SPARKX3, SPARKX4, SPARKX5, SPARKX6, SPARKX7, SPARKX8, SPARKX9, SPARKX10, SPARKX11, SPARKX12, SPARKX13, SPARKX14, SPARKX15, SPARKX16, SPARKX17, SPARKX18, SPARKX19, SPARKX20: SPARKX-LOGO4; SPARKX-MEDIUM
U1, U13, U20, U27, U34, U41, U48, U55, U62, U69, U76, U83, U90, U97, U104, U111, U118, U125, U132, U139: ADM4210-1; TSOT6
U2, U11, U18, U25, U32, U39, U46, U53, U60, U67, U74, U81, U88, U95, U102, U109, U116, U123, U130, U137: 1.8V/100mA; SC70
U3, U8, U15, U22, U29, U36, U43, U50, U57, U64, U71, U78, U85, U92, U99, U106, U113, U120, U127, U134: ARTIC_R2; QFN-48
U4, U9, U16, U23, U30, U37, U44, U51, U58, U65, U72, U79, U86, U93, U100, U107, U114, U121, U128, U135: RFPA0133; QFN50P300X300X86-17N
U5, U10, U17, U24, U31, U38, U45, U52, U59, U66, U73, U80, U87, U94, U101, U108, U115, U122, U129, U136: AS179-92LF; SOT65P220X100-6N
U6, U12, U19, U26, U33, U40, U47, U54, U61, U68, U75, U82, U89, U96, U103, U110, U117, U124, U131, U138: 3.0V; SOT23-5
U7, U14, U21, U28, U35, U42, U49, U56, U63, U70, U77, U84, U91, U98, U105, U112, U119, U126, U133, U140: SST25VF020BUSON; USON_3X2MM
U$1, U$3, U$4, U$5, U$28, U$29, U$30, U$31, U$54, U$55, U$56, U$57, U$80, U$81, U$82, U$83, U$106, U$107, U$108, U$109, U$132, U$133, U$134, U$135, U$158, U$159, U$160, U$161, U$184, U$185, U$186, U$187, U$210, U$211, U$212, U$213, U$236, U$237, U$238, U$239, U$262, U$263, U$264, U$265, U$288, U$289, U$290, U$291, U$314, U$315, U$316, U$317, U$340, U$341, U$342, U$343, U$366, U$367, U$368, U$369, U$392, U$393, U$394, U$395, U$418, U$419, U$420, U$421, U$444, U$445, U$446, U$447, U$470, U$471, U$472, U$473, U$496, U$497, U$498, U$499: #GND#0
U$2, U$27, U$53, U$79, U$105, U$131, U$157, U$183, U$209, U$235, U$261, U$287, U$313, U$339, U$365, U$391, U$417, U$443, U$469, U$495: 10
U$6, U$32, U$58, U$84, U$110, U$136, U$162, U$188, U$214, U$240, U$266, U$292, U$318, U$344, U$370, U$396, U$422, U$448, U$474, U$500: #PWR_EN#0
U$7, U$33, U$59, U$85, U$111, U$137, U$163, U$189, U$215, U$241, U$267, U$293, U$319, U$345, U$371, U$397, U$423, U$449, U$475, U$501: #VIN#0
U$8, U$52, U$78, U$104, U$130, U$156, U$182, U$208, U$234, U$260, U$286, U$312, U$338, U$364, U$390, U$416, U$442, U$468, U$494, U$520: #FLASH_PWR#0
U$9, U$34, U$60, U$86, U$112, U$138, U$164, U$190, U$216, U$242, U$268, U$294, U$320, U$346, U$372, U$398, U$424, U$450, U$476, U$502: #FLSH_SCLK#0
U$10, U$35, U$61, U$87, U$113, U$139, U$165, U$191, U$217, U$243, U$269, U$295, U$321, U$347, U$373, U$399, U$425, U$451, U$477, U$503: #FLSH_SI#0
U$11, U$37, U$63, U$89, U$115, U$141, U$167, U$193, U$219, U$245, U$271, U$297, U$323, U$349, U$375, U$401, U$427, U$453, U$479, U$505: #FLSH_SO#0
U$12, U$36, U$62, U$88, U$114, U$140, U$166, U$192, U$218, U$244, U$270, U$296, U$322, U$348, U$374, U$400, U$426, U$452, U$478, U$504: #FLSH_CEN#0
U$13, U$38, U$64, U$90, U$116, U$142, U$168, U$194, U$220, U$246, U$272, U$298, U$324, U$350, U$376, U$402, U$428, U$454, U$480, U$506: #3#3V_OUT#0
U$14, U$39, U$65, U$91, U$117, U$143, U$169, U$195, U$221, U$247, U$273, U$299, U$325, U$351, U$377, U$403, U$429, U$455, U$481, U$507: #ANTENNA#0
U$15, U$40, U$66, U$92, U$118, U$144, U$170, U$196, U$222, U$248, U$274, U$300, U$326, U$352, U$378, U$404, U$430, U$456, U$482, U$508: #G8#0
U$16, U$41, U$67, U$93, U$119, U$145, U$171, U$197, U$223, U$249, U$275, U$301, U$327, U$353, U$379, U$405, U$431, U$457, U$483, U$509: #3#0V_OUT#0
U$17, U$42, U$68, U$94, U$120, U$146, U$172, U$198, U$224, U$250, U$276, U$302, U$328, U$354, U$380, U$406, U$432, U$458, U$484, U$510: #BOOT#0
U$18, U$43, U$69, U$95, U$121, U$147, U$173, U$199, U$225, U$251, U$277, U$303, U$329, U$355, U$381, U$407, U$433, U$459, U$485, U$511: #INT1#0
U$19, U$44, U$70, U$96, U$122, U$148, U$174, U$200, U$226, U$252, U$278, U$304, U$330, U$356, U$382, U$408, U$434, U$460, U$486, U$512: #INT2#0
U$20, U$45, U$71, U$97, U$123, U$149, U$175, U$201, U$227, U$253, U$279, U$305, U$331, U$357, U$383, U$409, U$435, U$461, U$487, U$513: #RESETB#0
U$21, U$46, U$72, U$98, U$124, U$150, U$176, U$202, U$228, U$254, U$280, U$306, U$332, U$358, U$384, U$410, U$436, U$462, U$488, U$514: #CS#0
U$22, U$47, U$73, U$99, U$125, U$151, U$177, U$203, U$229, U$255, U$281, U$307, U$333, U$359, U$385, U$411, U$437, U$463, U$489, U$515: #SCLK#0
U$23, U$48, U$74, U$100, U$126, U$152, U$178, U$204, U$230, U$256, U$282, U$308, U$334, U$360, U$386, U$412, U$438, U$464, U$490, U$516: #COPI#0
U$24, U$49, U$75, U$101, U$127, U$153, U$179, U$205, U$231, U$257, U$283, U$309, U$335, U$361, U$387, U$413, U$439, U$465, U$491, U$517: #CIPO#0
U$25, U$50, U$76, U$102, U$128, U$154, U$180, U$206, U$232, U$258, U$284, U$310, U$336, U$362, U$388, U$414, U$440, U$466, U$492, U$518: #1#8V_OUT#0
U$26, U$51, U$77, U$103, U$129, U$155, U$181, U$207, U$233, U$259, U$285, U$311, U$337, U$363, U$389, U$415, U$441, U$467, U$493, U$519: ARTIC_R20
X1, X2, X3, X4, X5, X6, X7, X8, X9, X10, X11, X12, X13, X14, X15, X16, X17, X18, X19, X20: CRYSTAL-TCXO-26MHZ; CRYSTAL-TCXO-SMD-1.65X1.25

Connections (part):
1.8V: C4.1, J11.1, L2.2, L4.2, L9.2, L13.2, L14.2, U2.5
1.8V1: C53.1, J37.1, L16.2, L18.2, L20.2, L22.2, L29.2, U11.5
1.8V2: C102.1, J62.1, L31.2, L33.2, L35.2, L37.2, L44.2, U18.5
1.8V3: C151.1, J87.1, L46.2, L48.2, L50.2, L52.2, L59.2, U25.5
1.8V4: C200.1, J112.1, L61.2, L63.2, L65.2, L67.2, L74.2, U32.5
1.8V5: C249.1, J137.1, L76.2, L78.2, L80.2, L82.2, L89.2, U39.5
1.8V6: C298.1, J162.1, L91.2, L93.2, L95.2, L97.2, L104.2, U46.5
1.8V7: C347.1, J187.1, L106.2, L108.2, L110.2, L112.2, L119.2, U53.5
1.8V8: C396.1, J212.1, L121.2, L123.2, L125.2, L127.2, L134.2, U60.5
1.8V9: C445.1, J237.1, L136.2, L138.2, L140.2, L142.2, L149.2, U67.5
1.8V10: C494.1, J262.1, L151.2, L153.2, L155.2, L157.2, L164.2, U74.5
1.8V11: C543.1, J287.1, L166.2, L168.2, L170.2, L172.2, L179.2, U81.5
1.8V12: C592.1, J312.1, L181.2, L183.2, L185.2, L187.2, L194.2, U88.5
1.8V13: C641.1, J337.1, L196.2, L198.2, L200.2, L202.2, L209.2, U95.5
1.8V14: C690.1, J362.1, L211.2, L213.2, L215.2, L217.2, L224.2, U102.5
1.8V15: C739.1, J387.1, L226.2, L228.2, L230.2, L232.2, L239.2, U109.5
1.8V16: C788.1, J412.1, L241.2, L243.2, L245.2, L247.2, L254.2, U116.5
1.8V17: C837.1, J437.1, L256.2, L258.2, L260.2, L262.2, L269.2, U123.5
1.8V18: C886.1, J462.1, L271.2, L273.2, L275.2, L277.2, L284.2, U130.5
1.8V19: C935.1, J487.1, L286.2, L288.2, L290.2, L292.2, L299.2, U137.5
ANTENNA: C37.1, J23.1, J25.FEED
ANTENNA1: C52.1, J26.FEED, J49.1
ANTENNA2: C101.1, J51.FEED, J74.1
ANTENNA3: C150.1, J76.FEED, J99.1
ANTENNA4: C199.1, J101.FEED, J124.1
ANTENNA5: C248.1, J126.FEED, J149.1
ANTENNA6: C297.1, J151.FEED, J174.1
ANTENNA7: C346.1, J176.FEED, J199.1
ANTENNA8: C395.1, J201.FEED, J224.1
ANTENNA9: C444.1, J226.FEED, J249.1
ANTENNA10: C493.1, J251.FEED, J274.1
ANTENNA11: C542.1, J276.FEED, J299.1
ANTENNA12: C591.1, J301.FEED, J324.1
ANTENNA13: C640.1, J326.FEED, J349.1
ANTENNA14: C689.1, J351.FEED, J374.1
ANTENNA15: C738.1, J376.FEED, J399.1
ANTENNA16: C787.1, J401.FEED, J424.1
ANTENNA17: C836.1, J426.FEED, J449.1
ANTENNA18: C885.1, J451.FEED, J474.1
ANTENNA19: C934.1, J476.FEED, J499.1
BOOT: J3.1, R5.1, U3.46
BOOT1: J28.1, R10.1, U8.46
BOOT2: J53.1, R26.1, U15.46
BOOT3: J78.1, R38.1, U22.46
BOOT4: J103.1, R50.1, U29.46
BOOT5: J128.1, R62.1, U36.46
BOOT6: J153.1, R74.1, U43.46
BOOT7: J178.1, R86.1, U50.46
BOOT8: J203.1, R98.1, U57.46
BOOT9: J228.1, R110.1, U64.46
BOOT10: J253.1, R122.1, U71.46
BOOT11: J278.1, R134.1, U78.46
BOOT12: J303.1, R146.1, U85.46
BOOT13: J328.1, R158.1, U92.46
BOOT14: J353.1, R170.1, U99.46
BOOT15: J378.1, R182.1, U106.46
BOOT16: J403.1, R194.1, U113.46
BOOT17: J428.1, R206.1, U120.46
BOOT18: J453.1, R218.1, U127.46
BOOT19: J478.1, R230.1, U134.46
CIPO: J10.1, U3.5
CIPO1: J36.1, U8.5
CIPO2: J61.1, U15.5
CIPO3: J86.1, U22.5
CIPO4: J111.1, U29.5
CIPO5: J136.1, U36.5
CIPO6: J161.1, U43.5
CIPO7: J186.1, U50.5
CIPO8: J211.1, U57.5
CIPO9: J236.1, U64.5
CIPO10: J261.1, U71.5
CIPO11: J286.1, U78.5
CIPO12: J311.1, U85.5
CIPO13: J336.1, U92.5
CIPO14: J361.1, U99.5
CIPO15: J386.1, U106.5
CIPO16: J411.1, U113.5
CIPO17: J436.1, U120.5
CIPO18: J461.1, U127.5
CIPO19: J486.1, U134.5
COPI: J9.1, U3.4
COPI1: J35.1, U8.4
COPI2: J60.1, U15.4
COPI3: J85.1, U22.4
COPI4: J110.1, U29.4
COPI5: J135.1, U36.4
COPI6: J160.1, U43.4
COPI7: J185.1, U50.4
COPI8: J210.1, U57.4
COPI9: J235.1, U64.4
COPI10: J260.1, U71.4
COPI11: J285.1, U78.4
COPI12: J310.1, U85.4
COPI13: J335.1, U92.4
COPI14: J360.1, U99.4
COPI15: J385.1, U106.4
COPI16: J410.1, U113.4
COPI17: J435.1, U120.4
COPI18: J460.1, U127.4
COPI19: J485.1, U134.4
CS: J7.1, U3.2
CS1: J33.1, U8.2
CS2: J58.1, U15.2
CS3: J83.1, U22.2
CS4: J108.1, U29.2
CS5: J133.1, U36.2
CS6: J158.1, U43.2
CS7: J183.1, U50.2
CS8: J208.1, U57.2
CS9: J233.1, U64.2
CS10: J258.1, U71.2
CS11: J283.1, U78.2
CS12: J308.1, U85.2
CS13: J333.1, U92.2
CS14: J358.1, U99.2
CS15: J383.1, U106.2
CS16: J408.1, U113.2
CS17: J433.1, U120.2
CS18: J458.1, U127.2
CS19: J483.1, U134.2
FLASH_PWR: J16.1, L1.2
FLASH_PWR1: J42.1, L30.2
FLASH_PWR2: J67.1, L45.2
FLASH_PWR3: J92.1, L60.2
FLASH_PWR4: J117.1, L75.2
FLASH_PWR5: J142.1, L90.2
FLASH_PWR6: J167.1, L105.2
FLASH_PWR7: J192.1, L120.2
FLASH_PWR8: J217.1, L135.2
FLASH_PWR9: J242.1, L150.2
FLASH_PWR10: J267.1, L165.2
FLASH_PWR11: J292.1, L180.2
FLASH_PWR12: J317.1, L195.2
FLASH_PWR13: J342.1, L210.2
FLASH_PWR14: J367.1, L225.2
FLASH_PWR15: J392.1, L240.2
FLASH_PWR16: J417.1, L255.2
FLASH_PWR17: J442.1, L270.2
FLASH_PWR18: J467.1, L285.2
FLASH_PWR19: J492.1, L300.2
FLASH_VCC: C50.1, L1.1, U7.3, U7.7, U7.8
FLASH_VCC1: C98.1, L30.1, U14.3, U14.7, U14.8
FLASH_VCC2: C147.1, L45.1, U21.3, U21.7, U21.8
FLASH_VCC3: C196.1, L60.1, U28.3, U28.7, U28.8
FLASH_VCC4: C245.1, L75.1, U35.3, U35.7, U35.8
FLASH_VCC5: C294.1, L90.1, U42.3, U42.7, U42.8
FLASH_VCC6: C343.1, L105.1, U49.3, U49.7, U49.8
FLASH_VCC7: C392.1, L120.1, U56.3, U56.7, U56.8
FLASH_VCC8: C441.1, L135.1, U63.3, U63.7, U63.8
FLASH_VCC9: C490.1, L150.1, U70.3, U70.7, U70.8
FLASH_VCC10: C539.1, L165.1, U77.3, U77.7, U77.8
FLASH_VCC11: C588.1, L180.1, U84.3, U84.7, U84.8
FLASH_VCC12: C637.1, L195.1, U91.3, U91.7, U91.8
FLASH_VCC13: C686.1, L210.1, U98.3, U98.7, U98.8
FLASH_VCC14: C735.1, L225.1, U105.3, U105.7, U105.8
FLASH_VCC15: C784.1, L240.1, U112.3, U112.7, U112.8
FLASH_VCC16: C833.1, L255.1, U119.3, U119.7, U119.8
FLASH_VCC17: C882.1, L270.1, U126.3, U126.7, U126.8
FLASH_VCC18: C931.1, L285.1, U133.3, U133.7, U133.8
FLASH_VCC19: C980.1, L300.1, U140.3, U140.7, U140.8
FLSH_CEN: J21.1, U3.15, U7.1
FLSH_CEN1: J47.1, U8.15, U14.1
FLSH_CEN2: J72.1, U15.15, U21.1
FLSH_CEN3: J97.1, U22.15, U28.1
FLSH_CEN4: J122.1, U29.15, U35.1
FLSH_CEN5: J147.1, U36.15, U42.1
FLSH_CEN6: J172.1, U43.15, U49.1
FLSH_CEN7: J197.1, U50.15, U56.1
FLSH_CEN8: J222.1, U57.15, U63.1
FLSH_CEN9: J247.1, U64.15, U70.1
FLSH_CEN10: J272.1, U71.15, U77.1
FLSH_CEN11: J297.1, U78.15, U84.1
FLSH_CEN12: J322.1, U85.15, U91.1
FLSH_CEN13: J347.1, U92.15, U98.1
FLSH_CEN14: J372.1, U99.15, U105.1
FLSH_CEN15: J397.1, U106.15, U112.1
FLSH_CEN16: J422.1, U113.15, U119.1
FLSH_CEN17: J447.1, U120.15, U126.1
FLSH_CEN18: J472.1, U127.15, U133.1
FLSH_CEN19: J497.1, U134.15, U140.1
FLSH_SCLK: J18.1, U3.12, U7.6
FLSH_SCLK1: J44.1, U8.12, U14.6
FLSH_SCLK2: J69.1, U15.12, U21.6
FLSH_SCLK3: J94.1, U22.12, U28.6
FLSH_SCLK4: J119.1, U29.12, U35.6
FLSH_SCLK5: J144.1, U36.12, U42.6
FLSH_SCLK6: J169.1, U43.12, U49.6
FLSH_SCLK7: J194.1, U50.12, U56.6
FLSH_SCLK8: J219.1, U57.12, U63.6
FLSH_SCLK9: J244.1, U64.12, U70.6
FLSH_SCLK10: J269.1, U71.12, U77.6
FLSH_SCLK11: J294.1, U78.12, U84.6
FLSH_SCLK12: J319.1, U85.12, U91.6
FLSH_SCLK13: J344.1, U92.12, U98.6
FLSH_SCLK14: J369.1, U99.12, U105.6
FLSH_SCLK15: J394.1, U106.12, U112.6
FLSH_SCLK16: J419.1, U113.12, U119.6
FLSH_SCLK17: J444.1, U120.12, U126.6
FLSH_SCLK18: J469.1, U127.12, U133.6
FLSH_SCLK19: J494.1, U134.12, U140.6
FLSH_SI: J19.1, U3.13, U7.5
FLSH_SI1: J45.1, U8.13, U14.5
FLSH_SI2: J70.1, U15.13, U21.5
FLSH_SI3: J95.1, U22.13, U28.5
FLSH_SI4: J120.1, U29.13, U35.5
FLSH_SI5: J145.1, U36.13, U42.5
FLSH_SI6: J170.1, U43.13, U49.5
FLSH_SI7: J195.1, U50.13, U56.5
FLSH_SI8: J220.1, U57.13, U63.5
FLSH_SI9: J245.1, U64.13, U70.5
FLSH_SI10: J270.1, U71.13, U77.5
FLSH_SI11: J295.1, U78.13, U84.5
FLSH_SI12: J320.1, U85.13, U91.5
FLSH_SI13: J345.1, U92.13, U98.5
FLSH_SI14: J370.1, U99.13, U105.5
FLSH_SI15: J395.1, U106.13, U112.5
FLSH_SI16: J420.1, U113.13, U119.5
FLSH_SI17: J445.1, U120.13, U126.5
FLSH_SI18: J470.1, U127.13, U133.5
FLSH_SI19: J495.1, U134.13, U140.5
FLSH_SO: J20.1, U3.14, U7.2
FLSH_SO1: J46.1, U8.14, U14.2
FLSH_SO2: J71.1, U15.14, U21.2
FLSH_SO3: J96.1, U22.14, U28.2
FLSH_SO4: J121.1, U29.14, U35.2
FLSH_SO5: J146.1, U36.14, U42.2
FLSH_SO6: J171.1, U43.14, U49.2
FLSH_SO7: J196.1, U50.14, U56.2
FLSH_SO8: J221.1, U57.14, U63.2
FLSH_SO9: J246.1, U64.14, U70.2
FLSH_SO10: J271.1, U71.14, U77.2
FLSH_SO11: J296.1, U78.14, U84.2
FLSH_SO12: J321.1, U85.14, U91.2
FLSH_SO13: J346.1, U92.14, U98.2
FLSH_SO14: J371.1, U99.14, U105.2
FLSH_SO15: J396.1, U106.14, U112.2
FLSH_SO16: J421.1, U113.14, U119.2
FLSH_SO17: J446.1, U120.14, U126.2
FLSH_SO18: J471.1, U127.14, U133.2
FLSH_SO19: J496.1, U134.14, U140.2
G1: J30.1, K2.1
G2: J55.1, K3.1
G3: J80.1, K4.1
G4: J105.1, K5.1
G5: J130.1, K6.1
G6: J155.1, K7.1
G7: J180.1, K8.1
G8: J1.1, K1.1
G9: J205.1, K9.1
G10: J230.1, K10.1
G11: J255.1, K11.1
G12: J280.1, K12.1
G13: J305.1, K13.1
G14: J330.1, K14.1
G15: J355.1, K15.1
G16: J380.1, K16.1
G17: J405.1, K17.1
G18: J430.1, K18.1
G19: J455.1, K19.1
G20: J480.1, K20.1
GND: C1.2, C2.2, C3.2, C4.2, C5.2, C6.2, C7.2, C8.2, C9.2, C10.2, C11.2, C12.2, C13.2, C14.2, C15.2, C16.2, C18.2, C19.2, C20.1, C21.1, C22.1, C23.2, C26.2, C27.2, C28.1, C32.2, C33.2, C34.2, C35.2, C36.2, C38.2, C39.2, C40.2, C41.2, C42.2, C43.1, C44.2, C45.2, C46.2, C48.2, C49.2, C50.2, J12.1, J13.1, J22.1, J24.1, J25.1, J25.2, K1.2, L11.P$1, L12.P$1, R4.2, R6.1, R7.2, R12.2, R14.1, SCREEN.1-1, SCREEN.1-16, SCREEN.2, SCREEN.3-1, SCREEN.3-16, SCREEN.4, U1.2, U2.2, U3.25, U3.27, U3.29, U3.30, U3.31, U3.32, U3.39, U3.GND, U4.2, U4.EDAP, U5.2, U6.2, U7.4, X1.1, X1.2
GND1: C53.2, C54.2, C55.2, C56.2, C57.2, C58.2, C59.2, C60.2, C61.2, C62.2, C63.2, C64.2, C65.2, C66.2, C67.2, C68.2, C69.2, C70.2, C71.2, C73.2, C74.2, C75.2, C78.1, C79.1, C80.1, C81.2, C82.2, C84.1, C85.2, C86.2, C87.2, C88.1, C89.2, C90.2, C91.2, C92.2, C93.2, C94.2, C95.2, C96.2, C97.2, C98.2, J26.1, J26.2, J38.1, J39.1, J48.1, J50.1, K2.2, L27.P$1, L28.P$1, R13.2, R15.1, R16.2, R19.1, R24.2, SCREEN1.1-1, SCREEN1.1-16, SCREEN1.2, SCREEN1.3-1, SCREEN1.3-16, SCREEN1.4, U8.25, U8.27, U8.29, U8.30, U8.31, U8.32, U8.39, U8.GND, U9.2, U9.EDAP, U10.2, U11.2, U12.2, U13.2, U14.4, X2.1, X2.2
GND2: C102.2, C103.2, C104.2, C105.2, C106.2, C107.2, C108.2, C109.2, C110.2, C111.2, C112.2, C113.2, C114.2, C115.2, C116.2, C117.2, C118.2, C119.2, C120.2, C122.2, C123.2, C124.2, C127.1, C128.1, C129.1, C130.2, C131.2, C133.1, C134.2, C135.2, C136.2, C137.1, C138.2, C139.2, C140.2, C141.2, C142.2, C143.2, C144.2, C145.2, C146.2, C147.2, J51.1, J51.2, J63.1, J64.1, J73.1, J75.1, K3.2, L42.P$1, L43.P$1, R27.2, R28.1, R29.2, R31.1, R36.2, SCREEN2.1-1, SCREEN2.1-16, SCREEN2.2, SCREEN2.3-1, SCREEN2.3-16, SCREEN2.4, U15.25, U15.27, U15.29, U15.30, U15.31, U15.32, U15.39, U15.GND, U16.2, U16.EDAP, U17.2, U18.2, U19.2, U20.2, U21.4, X3.1, X3.2
GND3: C151.2, C152.2, C153.2, C154.2, C155.2, C156.2, C157.2, C158.2, C159.2, C160.2, C161.2, C162.2, C163.2, C164.2, C165.2, C166.2, C167.2, C168.2, C169.2, C171.2, C172.2, C173.2, C176.1, C177.1, C178.1, C179.2, C180.2, C182.1, C183.2, C184.2, C185.2, C186.1, C187.2, C188.2, C189.2, C190.2, C191.2, C192.2, C193.2, C194.2, C195.2, C196.2, J76.1, J76.2, J88.1, J89.1, J98.1, J100.1, K4.2, L57.P$1, L58.P$1, R39.2, R40.1, R41.2, R43.1, R48.2, SCREEN3.1-1, SCREEN3.1-16, SCREEN3.2, SCREEN3.3-1, SCREEN3.3-16, SCREEN3.4, U22.25, U22.27, U22.29, U22.30, U22.31, U22.32, U22.39, U22.GND, U23.2, U23.EDAP, U24.2, U25.2, U26.2, U27.2, U28.4, X4.1, X4.2
GND4: C200.2, C201.2, C202.2, C203.2, C204.2, C205.2, C206.2, C207.2, C208.2, C209.2, C210.2, C211.2, C212.2, C213.2, C214.2, C215.2, C216.2, C217.2, C218.2, C220.2, C221.2, C222.2, C225.1, C226.1, C227.1, C228.2, C229.2, C231.1, C232.2, C233.2, C234.2, C235.1, C236.2, C237.2, C238.2, C239.2, C240.2, C241.2, C242.2, C243.2, C244.2, C245.2, J101.1, J101.2, J113.1, J114.1, J123.1, J125.1, K5.2, L72.P$1, L73.P$1, R51.2, R52.1, R53.2, R55.1, R60.2, SCREEN4.1-1, SCREEN4.1-16, SCREEN4.2, SCREEN4.3-1, SCREEN4.3-16, SCREEN4.4, U29.25, U29.27, U29.29, U29.30, U29.31, U29.32, U29.39, U29.GND, U30.2, U30.EDAP, U31.2, U32.2, U33.2, U34.2, U35.4, X5.1, X5.2
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

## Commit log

2020-12-14 Work in progress
    [ARTIC_R2_Module.brd, ARTIC_R2_Module.sch]
2020-12-15 Adding panel files. Updating README.
    [ARTIC_R2_Module-Panel.GBL, ARTIC_R2_Module-Panel.GBO, ARTIC_R2_Module-Panel.GBP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]
2020-12-15 Adding 50Ohms to the Antenna Pad
    [ARTIC_R2_Module.sch]
2020-12-16 Adding better castellated pads. Correcting cutouts for screen tabs.
    [ARTIC_R2_Module-Panel.brd, ARTIC_R2_Module.brd, ARTIC_R2_Module.sch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]
2020-12-18 Updated the screening can
    [ARTIC_R2_Module-Panel.brd, ARTIC_R2_Module.brd, ARTIC_R2_Module.sch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]
2020-12-18 Moved the X01 to make it visible
    [ARTIC_R2_Module-Panel.brd, ARTIC_R2_Module.brd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]
2021-01-12 Added the flash memory in USON format
    The flash has its own power pin so it can be programmed independantly - without needing the ARTIC to be powered up and held in reset. The user will need to jump the flash power pad across to the adjacent VDD pad on their board.
    [ARTIC_R2_Module-Panel.brd, ARTIC_R2_Module.brd, ARTIC_R2_Module.sch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]
2021-01-19 Adding missing PROD_IDs. Changed pad metal on layers 2 & 15 to polygons instead of rectangles (got rid of some errors).
    [ARTIC_R2_Module.brd, ARTIC_R2_Module.sch]
2021-09-07 Add BOM
    [IOTA_BOM.csv]
2021-11-22 Update Eagle files - remove New_Parts libraries
    [ARTIC_R2_Module.brd, ARTIC_R2_Module.sch, IOTA_BOM.csv]

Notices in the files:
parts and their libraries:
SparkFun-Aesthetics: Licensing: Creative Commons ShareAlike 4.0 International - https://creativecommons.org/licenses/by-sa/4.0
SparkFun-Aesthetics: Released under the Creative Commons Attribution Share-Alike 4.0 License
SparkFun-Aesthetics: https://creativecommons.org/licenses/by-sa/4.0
